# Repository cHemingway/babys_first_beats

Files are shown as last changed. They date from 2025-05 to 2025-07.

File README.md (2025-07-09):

## Baby's First Beats

Sample box for a very small child, to introduce them to DnB/Garage/Jungle etc

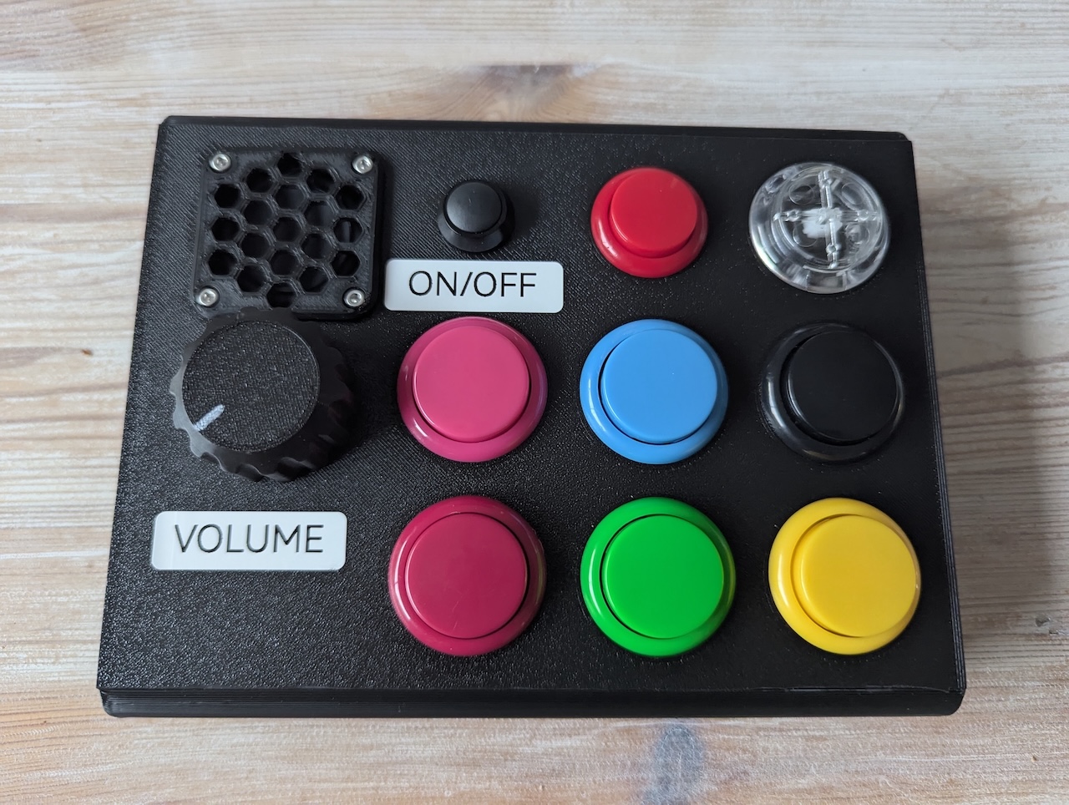
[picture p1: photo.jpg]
A photo of the finished device, lots of colorful buttons on a black box


### Hardware
- [Adafruit RP2040 Prop-Maker Feather](https://learn.adafruit.com/adafruit-rp2040-prop-maker-feather)
    - Modified to remove 10K pullup on EN pin
- [Mini speaker 4R 3W](https://shop.pimoroni.com/products/mini-speaker-4-3w)
- [2200mAh LiPo battery pack](https://shop.pimoroni.com/products/lithium-ion-battery-pack?variant=23417820359)
- [Colourful Arcade Buttons](https://shop.pimoroni.com/products/colourful-arcade-buttons?variant=451785353)
- 3D Printed Case, see /cad
- [Adafruit Micro SD SPI or SDIO Card Breakout Board - 3V ONLY!](https://www.adafruit.com/product/4682)
- [Adafruit Push Button Power Switch Breakout](https://www.adafruit.com/product/1400) Drives EN pin high to latch power on

### Code
- Runs on CircuitPython 9.0
- Hardware test project in `code/hw_test` 
- Actual code in `code/app`
    - Make sure to manually copy the contents of SD to your SD card with a proper card reader, you can't write to them over the CircuitPython USB interface

### Samples
- Samples from ross
- Loops: 
    - Diesel not Petrol - Sukh Night
    - [Wu Tang - Protect Ya Neck (Drum Loop) 103 BPM by Krem Drums](https://www.youtube.com/watch?v=_KVcPm7FgkQ)
    - The Next Episode (Instrumental) - Dr Dre

### Credits
- Many Adafruit models from [Adafruit CAD Parts](https://github.com/adafruit/Adafruit_CAD_Parts)
- Github Copilot for a lot of the more boring code

### TODO / Known Issues
- Read battery with external resistor divider
- Playing two audio files at once from the SD card has a chance of causing horrible glitching sounds until a power cycle. To fix this, we store the loops on the internal memory and the samples on the SD card.

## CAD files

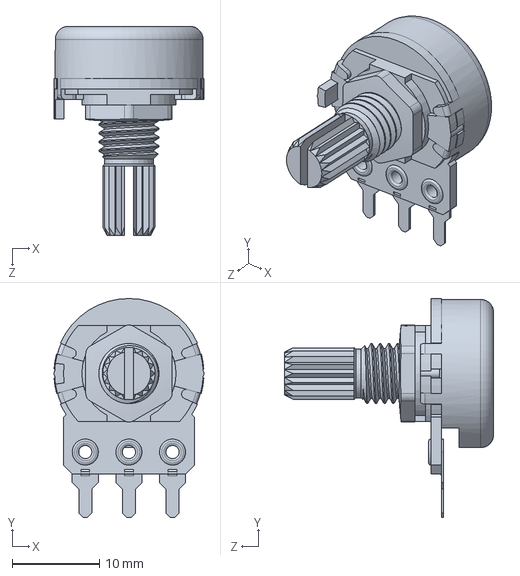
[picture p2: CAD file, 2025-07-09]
cad/3rd_party_cad/potentiometer.SLDPRT
17.2 x 25.1 x 24.0 mm

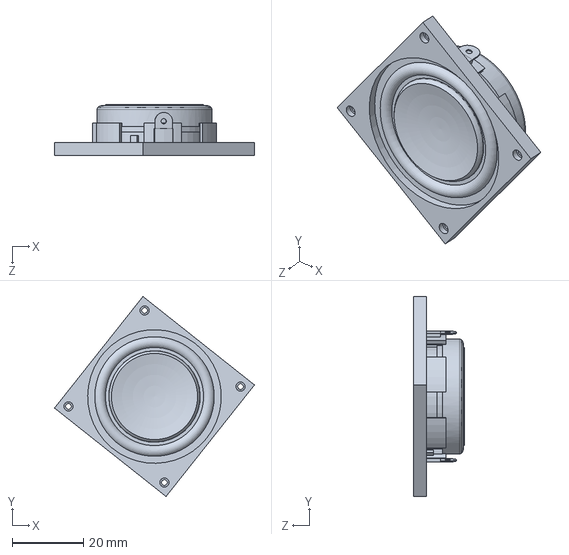
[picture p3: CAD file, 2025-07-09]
cad/Same_Sky_CSS-40408N.SLDPRT
56.3 x 56.3 x 14.5 mm

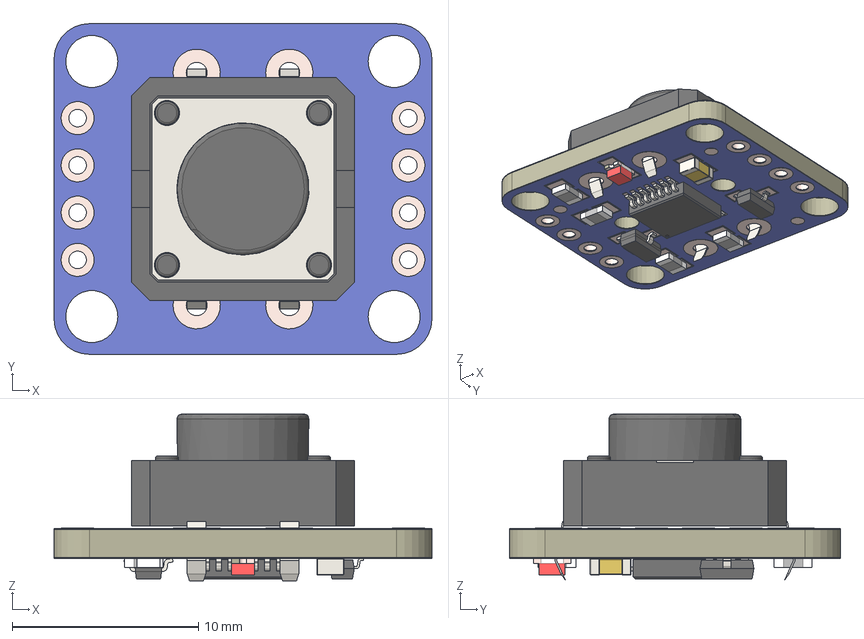
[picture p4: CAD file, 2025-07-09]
cad/3rd_party_cad/1400 Push Button Power Switch.step
20.3 x 17.8 x 8.96 mm
Copper (Bottom)
Copper (Top)
Soldermask (Bottom)
Soldermask (Top)
CHIP-LED0805
B3F-40XX-ROUND-3D
C0805-3D
35746670.f3d
SOT23-WIDE
SOT23-BEC-3D
R0805-3D x 4

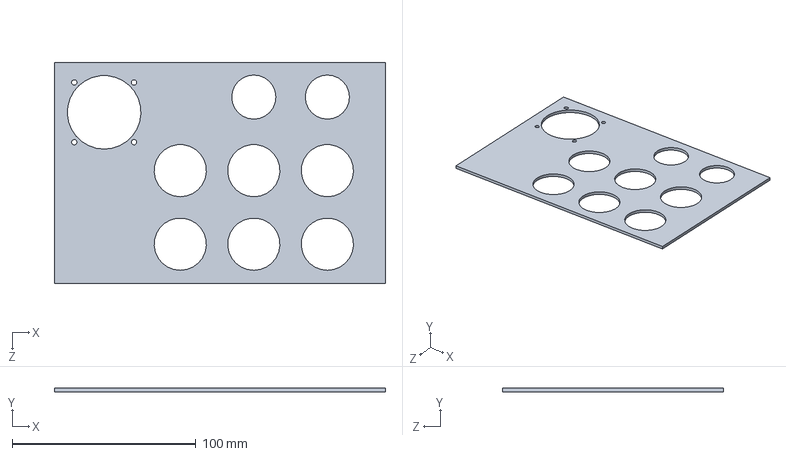
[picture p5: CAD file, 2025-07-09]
cad/front_panel_v1.SLDPRT
180.0 x 2.00 x 120.0 mm

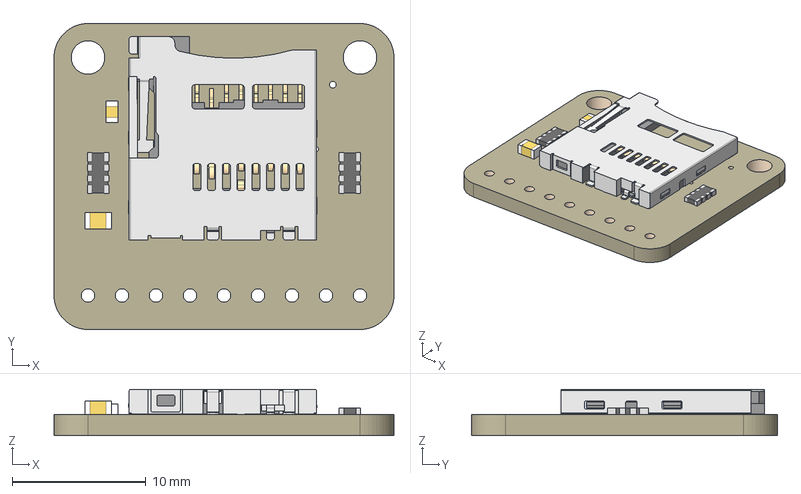
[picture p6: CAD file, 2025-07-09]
cad/3rd_party_cad/4682 Micro SD Breakout.step
25.4 x 22.9 x 3.45 mm
Board
microSD
10uF
0.1uF
47K x 2

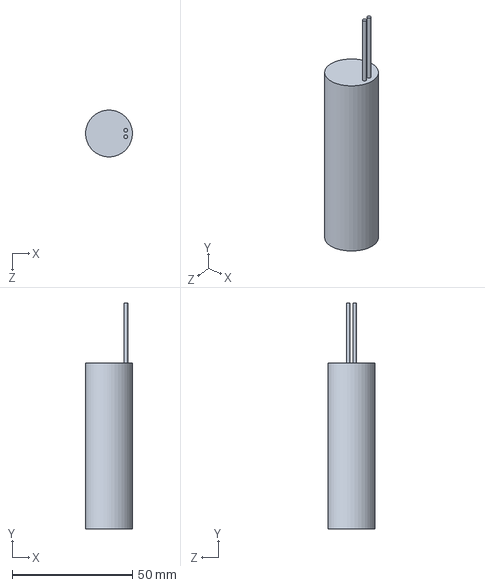
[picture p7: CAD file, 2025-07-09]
cad/PKCELL_ICR18650_Wired.SLDPRT
19.5 x 94.0 x 19.5 mm

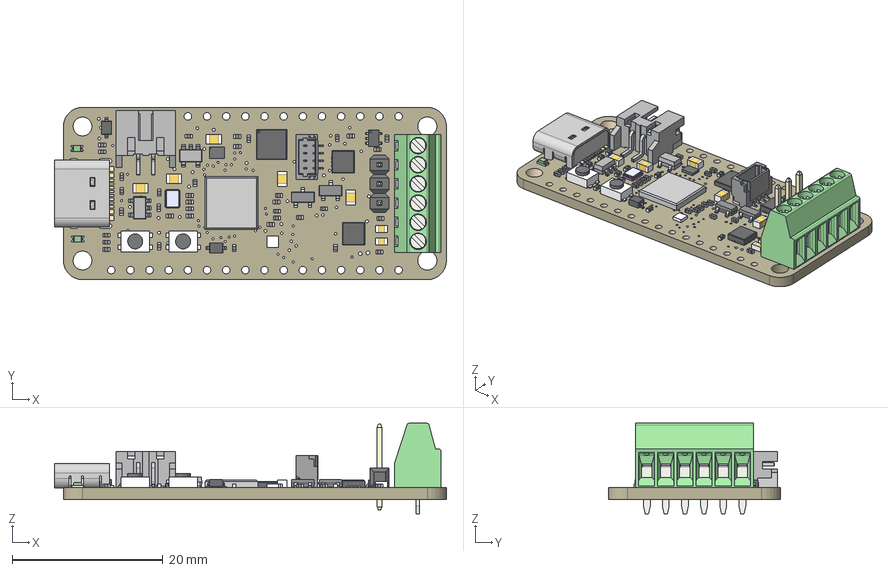
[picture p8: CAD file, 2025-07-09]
cad/3rd_party_cad/5768 Feather RP2040 PropMaker.step
52.0 x 22.9 x 12.0 mm
Board
10uF/16V x 5
ORANGE x 2
RKB2 x 2
RT9080-3.3
JSTPH
MCP73831T-2ACI/OT
WS2812B_SK6805_1515
8MB QSPI
PMEG2020AEA
DMG3415UFY
USB Type C
RP2040_QFN56
12MHz/12pF
1N4148
STEMMA_I2C_QTRA
74AHCT1G125DCK
LIS3DH
C20917 x 2
MAX98357A
Ferrite x 2
TERMINALS
1x3M

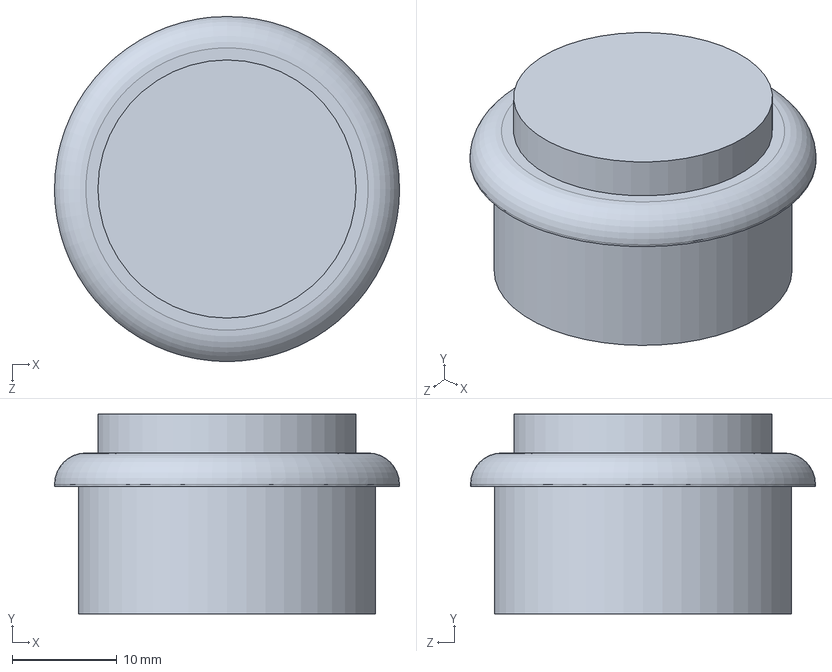
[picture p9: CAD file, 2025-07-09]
cad/arcade_button_large.SLDPRT
33.0 x 19.1 x 33.0 mm

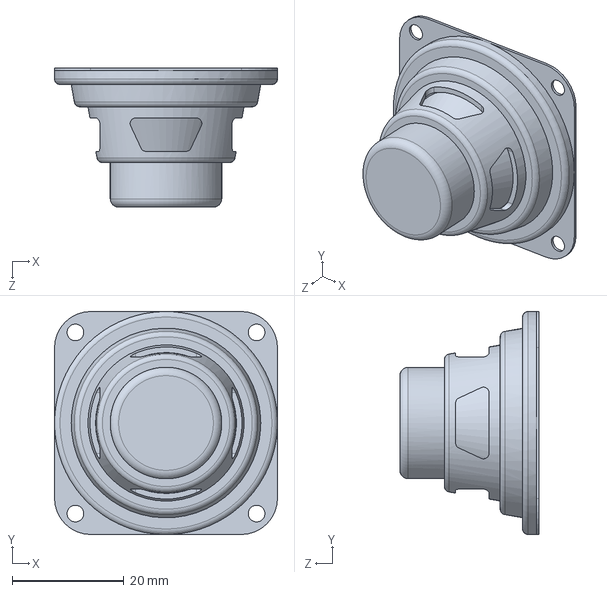
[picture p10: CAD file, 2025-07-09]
cad/3rd_party_cad/3968 Speaker 40mm.SLDPRT
40.0 x 40.0 x 25.0 mm

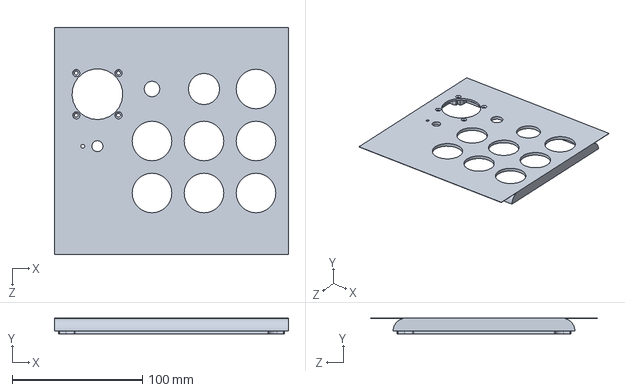
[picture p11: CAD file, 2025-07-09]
cad/case_split_top_v2.SLDPRT
180.0 x 12.0 x 174.4 mm

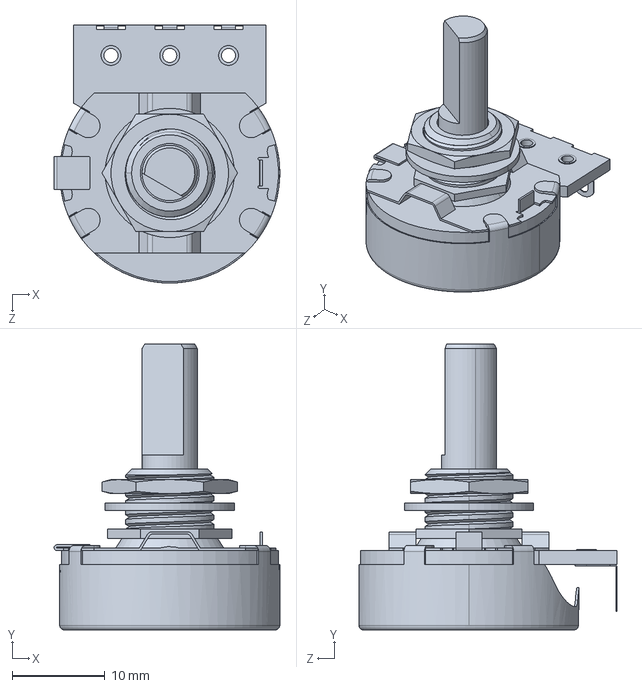
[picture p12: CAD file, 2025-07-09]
cad/3rd_party_cad/P231-FC20BR10K.SLDPRT
24.4 x 30.9 x 27.9 mm

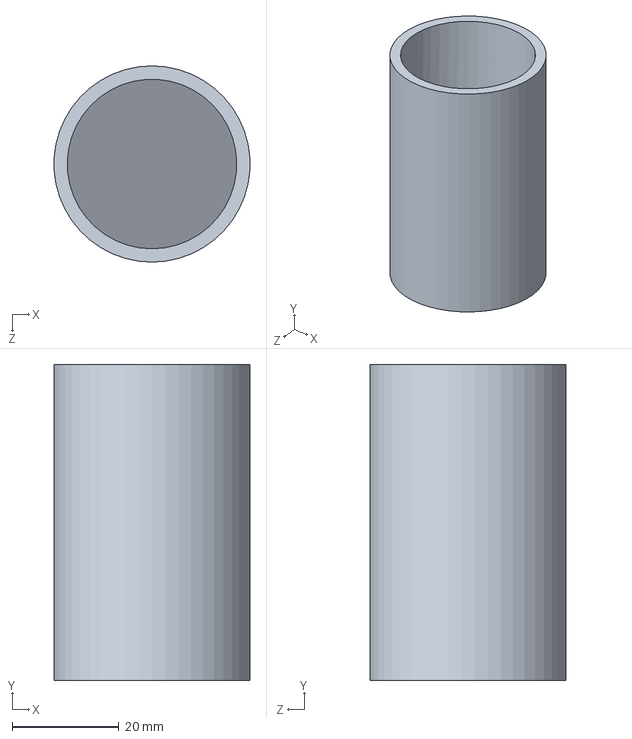
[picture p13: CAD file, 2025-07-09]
cad/Small Parts Choke Tester.SLDPRT
36.6 x 59.1 x 36.7 mm

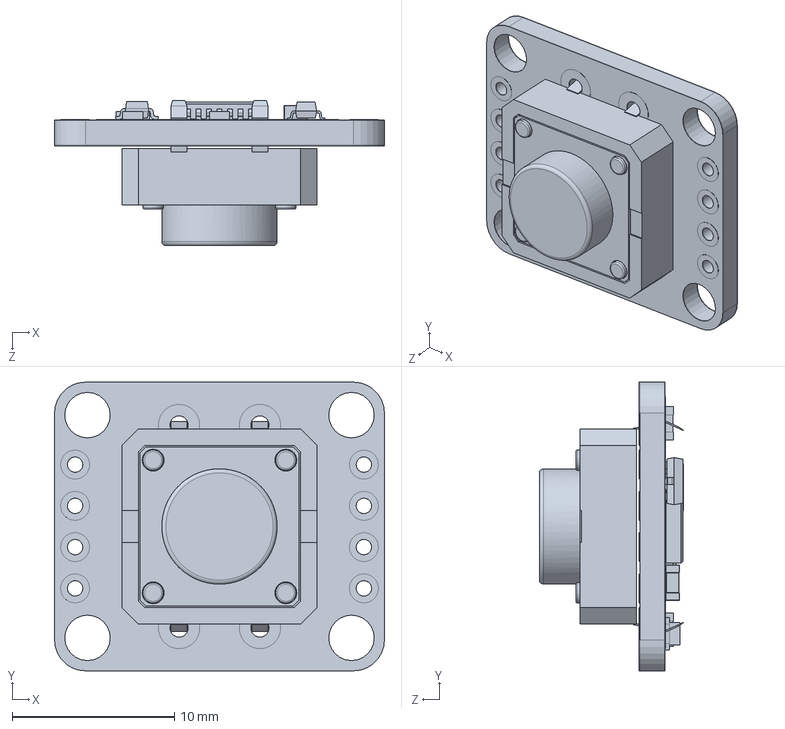
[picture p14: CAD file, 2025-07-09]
cad/1400 Push Button Power Switch.SLDPRT
20.3 x 17.8 x 8.96 mm

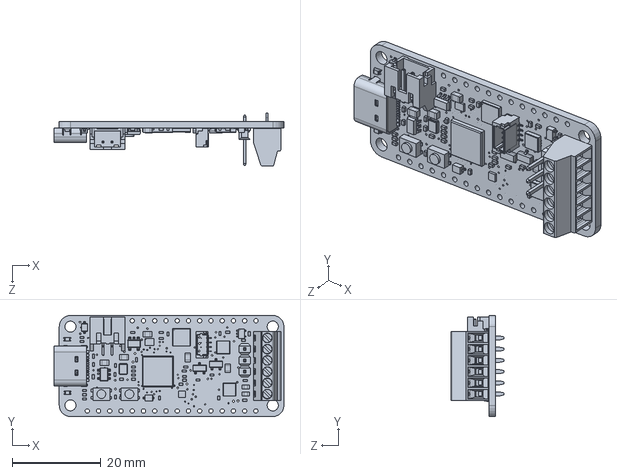
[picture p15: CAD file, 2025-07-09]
cad/5768 Feather RP2040 PropMaker.SLDPRT
52.0 x 22.9 x 12.0 mm

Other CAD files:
cad/assembly_v1.SLDASM
cad/langair_v12_antivandalswitch.SLDPRT
cad/4682 Micro SD Breakout.SLDPRT
cad/Volume Knob.SLDPRT
cad/SpeakerGrillV1.SLDPRT
cad/arcade_button_small.SLDPRT
cad/battery_clamp_v1.SLDPRT
cad/case_profile_extrusion.SLDPRT
cad/case_split_bottom.SLDPRT

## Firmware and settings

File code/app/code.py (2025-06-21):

import audiocore
import audiobusio
import audiomixer
import board
import time
import keypad

from digitalio import DigitalInOut, Direction
import analogio

import neopixel

import mount_sd

MAX_VOLUME = 0.25  # Maximum volume level, adjust as needed

from microcontroller import watchdog as w
from watchdog import WatchDogMode


print("Start")
start_time = time.monotonic_ns()

# Setup keypad
keypad = keypad.KeyMatrix(
    row_pins = [board.D5, board.D6, board.D9],
    column_pins = [board.D10, board.D11, board.D12],
)


# Volume control
volume_dial = analogio.AnalogIn(board.A0)
def get_volume():
    # Convert the raw value to a volume level between 0 and 1
    scale = volume_dial.value / 65535
    # Scale logarithmically to get a more natural volume curve
    volume = scale ** 1.4
    # Scale to maximum volume range
    volume = volume * MAX_VOLUME
    # Ensure volume is at least 0.025 to avoid silence
    volume = max(volume, 0.025)  
    return volume


# Table of button pins and audio files
# Note: Loops should be stored in local storage, samples should be on the SD card
# This avoid glitches/crashes from simultaneous access
KEY_DEFINITIONS_PIRATE = [
    {"key": 7, "type":"loop", "filename":   "/Diesel Not Petrol [-JqV1uJQaLU]_mono22k.wav"},
    {"key": 0, "type":"sample", "filename": "/sd/Worries Soundboy [2025-04-27 210147]_mono22k.wav"},
    {"key": 1, "type":"sample", "filename": "/sd/Killa Vox [2025-04-27 210139]_mono22k.wav"},
    {"key": 2, "type":"sample", "filename": "/sd/Ruling Bad Boy Tune [2025-04-27 210146]_mono22k.wav"},
    {"key": 3, "type":"sample", "filename": "/sd/Champion Badman [2025-04-27 210142]_mono22k.wav"},
    {"key": 4, "type":"sample", "filename": "/sd/bleep [2025-04-27 210136]_mono22k.wav"},
    {"key": 5, "type":"sample", "filename": "/sd/Air Horn Sound Effect [IpyingiCwV8]_mono22k.wav"}
]

KEY_DEFINITIONS_OLD_HIPHOP = [
    {"key": 7, "type":"loop", "filename":   "/Wu Tang - Protect Ya Neck (Drum Loop) 103 BPM [_KVcPm7FgkQ]_mono22k.wav"},
    {"key": 0, "type":"sample", "filename": "/sd/Effect (50) [2025-04-27 210132]_mono22k.wav"},
    {"key": 1, "type":"sample", "filename": "/sd/run_dmc_huh_mono22k.wav"},
    {"key": 2, "type":"sample", "filename": "/sd/wu-tang_clan_-_c.r.e.a.m._(complete_acapella) [2025-04-27 201019]_mono22k.wav"},
    {"key": 3, "type":"sample", "filename": "/sd/Scratch 2 b [2025-04-27 205203]_mono22k.wav"},
    {"key": 4, "type":"sample", "filename": "/sd/Scratch_Kick [2025-04-27 210138]_mono22k.wav"},
    {"key": 5, "type":"sample", "filename": "/sd/Null Reload [2025-04-27 210149]_mono22k.wav"},
]

KEY_DEFINITIONS_NEW_HIPHOP = [
    {"key": 7, "type":"loop", "filename":   "/The Next Episode (Instrumental)_mono22k.wav"},
    {"key": 0, "type":"sample", "filename": "/sd/Chant_02 [2025-04-27 210128]_mono22k.wav"},
    {"key": 1, "type":"sample", "filename": "/sd/Chant_03 [2025-04-27 210131]_mono22k.wav"},
    {"key": 2, "type":"sample", "filename": "/sd/pattalk2 [2025-04-27 210148]_mono22k.wav"},
    {"key": 3, "type":"sample", "filename": "/sd/dr.dre_-_next_episode_ft.snoop_dogg_(clean_acapella) [2025-04-27 201041]_mono22k.wav"},
    {"key": 4, "type":"sample", "filename": "/sd/dr.dre_-_next_episode_ft.snoop_dogg_(clean_acapella) [2025-04-27 201106]_mono22k.wav"},
    {"key": 5, "type":"sample", "filename": "/sd/dr.dre_-_next_episode_ft.snoop_dogg_(clean_acapella) [2025-04-27 201128]_mono22k.wav"},
]

KEY_DEFINITIONS_TOTAL = [
    {"color":(0x80,00,0x80), "defs":KEY_DEFINITIONS_PIRATE},
    {"color":(0xFF,0xFF,0x00), "defs":KEY_DEFINITIONS_OLD_HIPHOP},
    {"color":(0x00,0xFF,0x00), "defs":KEY_DEFINITIONS_NEW_HIPHOP}
]

# Setup neopixel
pixel = neopixel.NeoPixel(board.EXTERNAL_NEOPIXELS, 2, pixel_order=neopixel.GRBW)
pixel.brightness = 1
pixel.fill((0xFF,0x00,0x00))

# Setup audio mixer
audio = audiobusio.I2SOut(board.I2S_BIT_CLOCK, board.I2S_WORD_SELECT, board.I2S_DATA)
mixer = audiomixer.Mixer(voice_count=2, 
                         buffer_size=4096,  # Increased over 1024 to avoid buffer underruns
                         sample_rate=22050, channel_count=1,
                         bits_per_sample=16, samples_signed=True,)
volume = get_volume()
mixer.voice[0].level = volume   # Sample
mixer.voice[1].level = volume*0.5    # Loop
audio.play(mixer)

def currently_playing():
    ''' Check if any sound is currently playing '''
    for voice in mixer.voice:
        if voice.playing:
            return True
    return False

# Power off pin, connected to KILL external adafruit pushbutton power switch latch board 
# https://www.adafruit.com/product/1400
kill_power_pin = DigitalInOut(board.D13)
kill_power_pin.switch_to_output(value=False)

# External power pin
external_power = DigitalInOut(board.EXTERNAL_POWER)
external_power.direction = Direction.OUTPUT
external_power.value = True
end_time = time.monotonic_ns()

# Mount the SD card
print("Mounting SD card")
mount_sd.mount()

print(f"Setup time: {(end_time - start_time)*1E-6:.3f} ms")

# Start the watchdog timer
print("Starting watchdog timer")
w.timeout = 0.5
w.mode = WatchDogMode.RESET
w.feed()


print("Entering main loop")

# State variables
current_mode = KEY_DEFINITIONS_TOTAL[0]
pixel.fill(current_mode["color"])
current_loop = None
current_sample = None
last_played_time = time.monotonic()

while True:
    # Check for button presses
    if event := keypad.events.get():
        if event.pressed:
            # Check if the button is a mode change
            if event.key_number == 6:
                # Change the mode to the next one
                current_mode_index = KEY_DEFINITIONS_TOTAL.index(current_mode)
                current_mode_index = (current_mode_index + 1) % len(KEY_DEFINITIONS_TOTAL)
                current_mode = KEY_DEFINITIONS_TOTAL[current_mode_index]
                
                pixel.fill(current_mode["color"])
                # Stop any currently playing sound
                if current_sample:
                    mixer.voice[0].stop()
                    current_sample = None
                if current_loop:
                    mixer.voice[1].stop()
                    current_loop = None
                continue

            # Check if the button is a loop or sample
            for pin_def in current_mode["defs"]:
                if event.key_number == pin_def["key"]:
                    start_time = time.monotonic_ns()
                    # If the button is a loop
                    if pin_def["type"] == "loop":
                        # If the same loop is pressed again, stop it
                        if mixer.voice[1].playing and current_loop["key"] == pin_def["key"]:
                            print("Stopping current loop")
                            current_loop["wave"].deinit()
                            mixer.voice[1].stop()
                            current_loop = None
                        else: 
                            # Stop any currently playing sound
                            if mixer.voice[1].playing:
                                print("Stopping current loop")
                                current_loop["wave"].deinit()
                                mixer.voice[1].stop()
                                current_loop = None
                            # Load the new sound
                            pin_def["wave"] = audiocore.WaveFile(pin_def["filename"])
                            # Start the sound
                            mixer.voice[1].play(pin_def["wave"], loop=True)
                            current_loop = pin_def
                            last_played_time = time.monotonic()

                    elif pin_def["type"] == "sample":
                        # If the button is a sample, stop any currently playing sound
                        if mixer.voice[0].playing:
                            print("Stopping current sample")
                            current_sample["wave"].deinit() # Deinitialize the old wave file
                            mixer.voice[0].stop()
                        print(f"{pin_def['filename']}", end=" ")
                        # Load the new sound
                        print("Open", end=" ")
                        pin_def["wave"] = audiocore.WaveFile(pin_def["filename"])
                        # Start the sound
                        print("Play", end=" ")
                        mixer.voice[0].play(pin_def["wave"])
                        current_sample = pin_def
                        last_played_time = time.monotonic()
                        print("Playing")
                    else:
                        print(f"Unknown type {pin_def['type']} for {pin_def['filename']}")
                    end_time = time.monotonic_ns()
                    print(f"Latency: {(end_time - start_time)*1E-6:.3f} ms")

    # Check if the volume dial has changed
    volume = get_volume()
    if volume != mixer.voice[0].level:
        mixer.voice[0].level = volume * 1
        mixer.voice[1].level = volume * 0.75
    
    # Wait for the sound to finish
    if current_sample and not mixer.voice[0].playing:
        # Turn off the neopixel
        pixel.fill((0x00, 0x00, 0x00))
        current_sample = None

    # Turn off if no sound has been played for 10 minutes
    if not currently_playing() and (time.monotonic() - last_played_time > 600):
            print("No sound played for 10 minutes, turning off")
            external_power.value = False
            time.sleep(0.5)
            kill_power_pin.value = True
            print("Should now be off")
            while True:
                time.sleep(1)


    # Kick the LED as it takes a few goes to turn on
    pixel.fill(current_mode["color"])

    # Sleep for a short time to avoid busy waiting
    time.sleep(0.02)
    # Feed the watchdog timer
    w.feed()

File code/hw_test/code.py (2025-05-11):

import alarm
import audiocore
import audiobusio
import audiomixer
import board
import busio
import time

from digitalio import DigitalInOut, Direction, Pull

import neopixel
import adafruit_lis3dh

print("Start")

# Turn on neopixel
pixel = neopixel.NeoPixel(board.NEOPIXEL, 1)
pixel.brightness = 0.1

pixel.fill((0xFF,0xA5,0))

# Turn on external neopixel
external_pixel = neopixel.NeoPixel(board.EXTERNAL_NEOPIXEL, 1)
external_pixel.brightness = 0.1
external_pixel.fill((0xFF,0xA5,0))

# Speak to accelerometer
i2c = board.I2C()  # uses board.SCL and board.SDA
accel_int1 = DigitalInOut(board.ACCELEROMETER_INTERRUPT)
accel = adafruit_lis3dh.LIS3DH_I2C(i2c, int1=accel_int1)
accel.range = adafruit_lis3dh.RANGE_4_G


# Set tap detection to double taps.  The first parameter is a value:
#  - 0 = Disable tap detection.
#  - 1 = Detect single taps.
#  - 2 = Detect double taps.

# The second parameter is the threshold and a higher value means less sensitive
# tap detection.  Note the threshold should be set based on the range above:
#  - 2G = 40-80 threshold
#  - 4G = 20-40 threshold
#  - 8G = 10-20 threshold
#  - 16G = 5-10 threshold
accel.set_tap(1, 100)

# enable external power pin
# provides power to the external components
external_power = DigitalInOut(board.EXTERNAL_POWER)
external_power.direction = Direction.OUTPUT
external_power.value = True

print("Power On")

# i2s playback
wave_file = open("hypefunk - antonio - drumloop compressed_mono22k.wav", "rb")
wave = audiocore.WaveFile(wave_file)
audio = audiobusio.I2SOut(board.I2S_BIT_CLOCK, board.I2S_WORD_SELECT, board.I2S_DATA)
mixer = audiomixer.Mixer(voice_count=1, sample_rate=22050, channel_count=1,
                         bits_per_sample=16, samples_signed=True)
audio.play(mixer)
mixer.voice[0].level = 0.1
mixer.voice[0].play(wave, loop=False)
print("Playing")

#Keep LED on if playing
external_pixel.fill((0x00,0x00,0xFF))


while mixer.voice[0].playing:
    time.sleep(0.1)
    if accel.tapped:
        pixel.fill((0xFF,0xFF,0xFF))
    else:
        pixel.fill((0x00,0x00,0xFF))


external_pixel.fill((0x00, 0xFF, 0x00))
print("Done")

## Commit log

2025-05-14 Turn power off if not been used in 10 minutes
2025-05-14 Add SD card and move sound samples there
2025-05-14 Add minimum volume to avoid silence
    [code.py]
2025-05-17 Attempt to fix audio glitches
    Slow down loop and increase buffer sizes.
    [code.py]
2025-05-17 Hack: watchdog timer to stop audio glitches quickly by rebooting
    [code.py]
2025-05-17 Cleanup current_loop logic, add lots of debugging prints
2025-05-18 Move loops to SPI flash from SD card
    Avoids glitches/crashes from simulataneous access
    [code.py]
2025-05-18 Set mode LED every time
2025-06-21 Change old school hiphop sample. Add newer hiphop samples
2025-07-09 Add CAD, update README.md
    [1400 Push Button Power Switch.SLDPRT, 1400 Push Button Power Switch.step, 3968 Speaker 40mm.SLDPRT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]
